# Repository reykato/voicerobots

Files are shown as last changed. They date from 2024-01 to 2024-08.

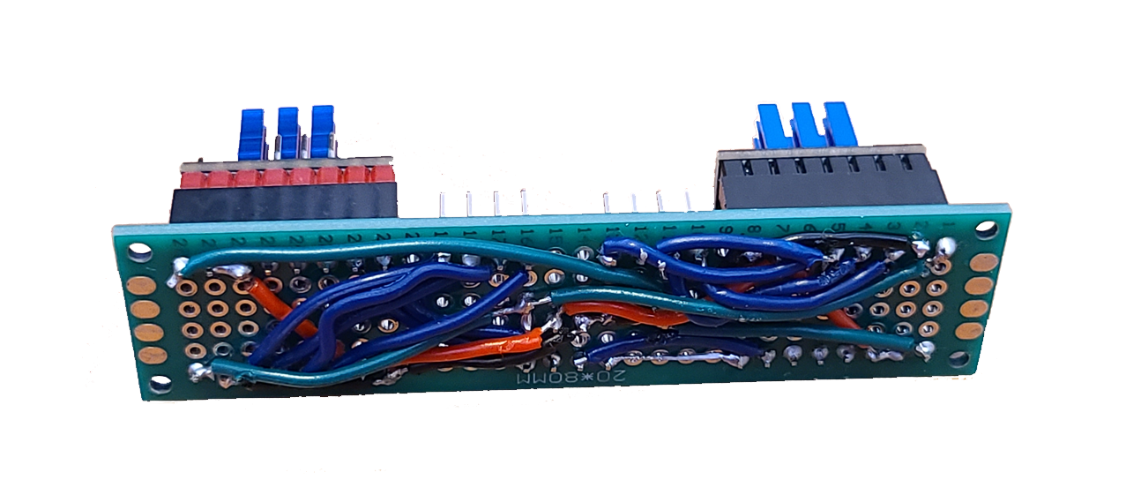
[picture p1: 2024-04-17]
images/stepper_driver_board_2.png

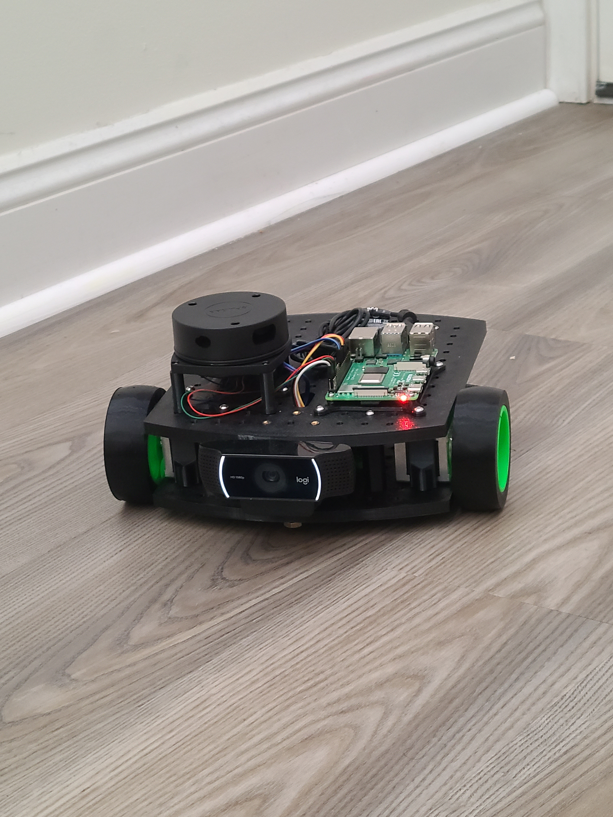
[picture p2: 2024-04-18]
images/robot/20240418_110335.jpg

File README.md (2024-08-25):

# Voice-Controlled Robot with Computer Vision
### CMPSC 488 Senior Capstone Design Project, Penn State Harrisburg, Spring 2024

#### Group Members
Japheth Beiler<br>
Tyler Lindsay<br>
Gabriel Marx

#### Faculty Advisors
Dr. Truong Tran<br>
Dr. Sayed Reza

This project won first prize out of 14 Computer Science projects at the PSU Harrisburg Capstone Design Conference.<br>

This repository is the main repository for this project. The server-side code is held in another repository available here: https://github.com/reykato/voicerobots-server

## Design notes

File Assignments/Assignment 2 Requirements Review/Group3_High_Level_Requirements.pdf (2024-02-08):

Voice-Demanded Robot Project
Group 3: Japheth Beiler, Tyler Lindsay, Gabriel Marx Technical Advisor: Dr. Truong Tran
Faculty Advisor: Dr. Sayed Reza
Fall 2023 - Spring 2024

High Level Requirements

- Filter audio input for easier audio transcription
- Obey direct navigational voice commands
- Use text generative AI to interpret commands that are not specified
- Navigate to specific colored targets
- Reroute navigation around obstacles identified by LiDAR
- Host website with manual joystick-style controls
- Stream live video of the robot’s view to the website
- Stream live 2D point cloud generated by LiDAR to website
- Draw decision-making symbols and lines on the live video to show how the robot “thinks”
- Ability to attach a towable device for transporting supplies

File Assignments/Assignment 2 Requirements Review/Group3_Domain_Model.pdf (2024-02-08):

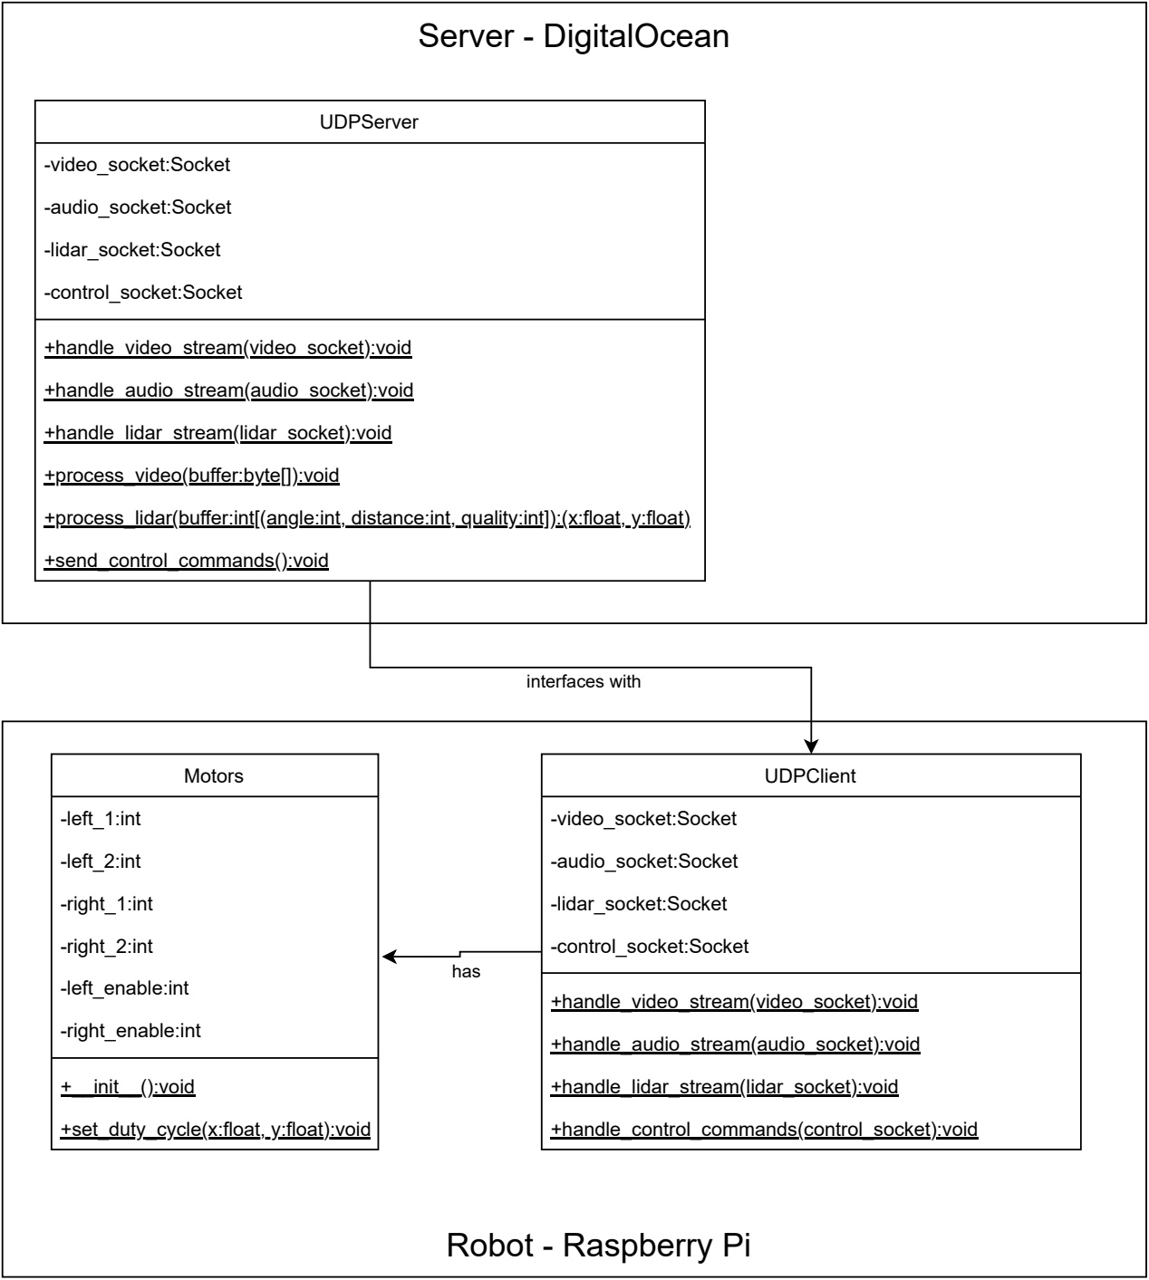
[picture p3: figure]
Motors; -left_1:int; -left_2:int; -right_1:int; -right_2:int; -left_enable:int; -right_enable:int; +__init__():void; +set_duty_cycle(x:float, y:float):void; Robot - Raspberry Pi; UDPClient; -video_socket:Socket; -audio_socket:Socket; -lidar_socket:Socket; -control_socket:Socket; +handle_video_stream(video_socket):void; +handle_audio_stream(audio_socket):void; +handle_lidar_stream(lidar_socket):void; Server - DigitalOcean; interfaces with; UDPServer; +process_video(buffer:byte[]):void; +send_control_commands():void; has

+handle_control_commands(control_socket):void

+process_lidar(buffer:int[(angle:int, distance:int, quality:int]):(x:float, y:float)

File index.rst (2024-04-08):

.. Voice-controlled Robot with Autonomous Navigation documentation master file, created by
   sphinx-quickstart on Sat Apr  6 20:12:07 2024.
   You can adapt this file completely to your liking, but it should at least
   contain the root `toctree` directive.

Welcome to Voice-controlled Robot with Autonomous Navigation's documentation!
=============================================================================

.. automodule:: stream
   :members:
   :undoc-members:
   
.. automodule:: audiostream
   :members:
   :undoc-members:
   
.. automodule:: controlstream
   :members:
   :undoc-members:
   
.. automodule:: videostream
   :members:
   :undoc-members:
   
.. automodule:: lidarstream
   :members:
   :undoc-members:
   
.. automodule:: motors
   :members:
   :undoc-members:

.. toctree::
   :maxdepth: 2
   :caption: Contents:

Indices and tables
==================

* :ref:`genindex`
* :ref:`modindex`
* :ref:`search`

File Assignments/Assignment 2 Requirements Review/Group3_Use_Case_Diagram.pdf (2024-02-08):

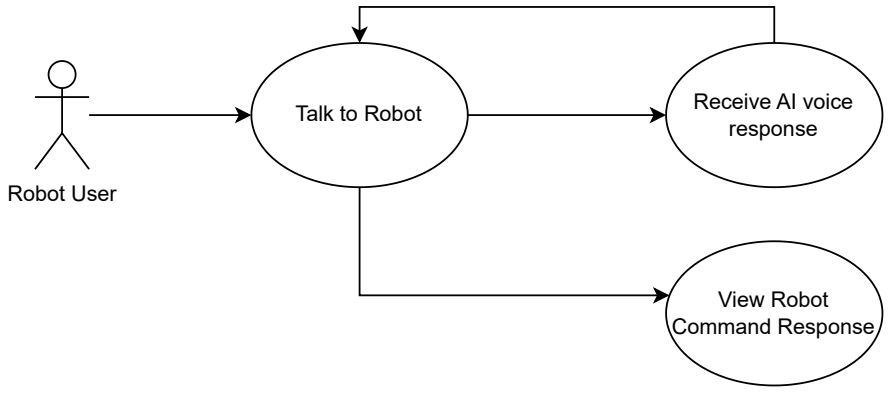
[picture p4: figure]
Robot User; Talk to Robot; View Robot Command Response; Receive AI voice response

Talk to Robot

A Robot User will be able to talk to the robot. The robot will listen using a live audio feed and send the audio data to the server. The server will intuit the speech and either issue a direct command to the robot, or respond in natural language.

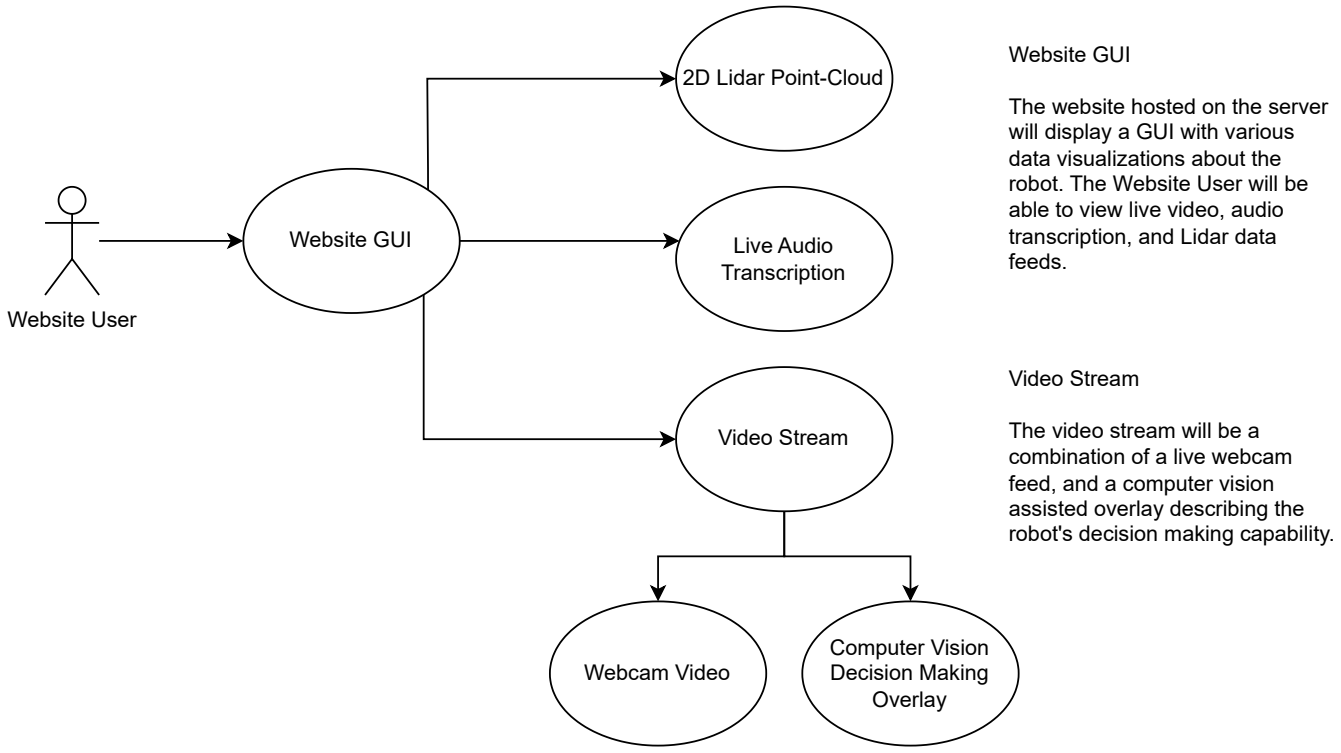
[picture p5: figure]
Website User; Video Stream; 2D Lidar Point-Cloud; Live Audio Transcription; Website GUI; The website hosted on the server will display a GUI with various data visualizations about the robot. The Website User will be able to view live video, audio transcription, and Lidar data feeds.; Webcam Video; Computer Vision Decision Making Overlay; The video stream will be a combination of a live webcam feed, and a computer vision assisted overlay describing the robot's decision making capability.

Robot Manual Controls

An authenticated Website
Administrator will be able to use joystick style controls to issue manual commands to the robot.

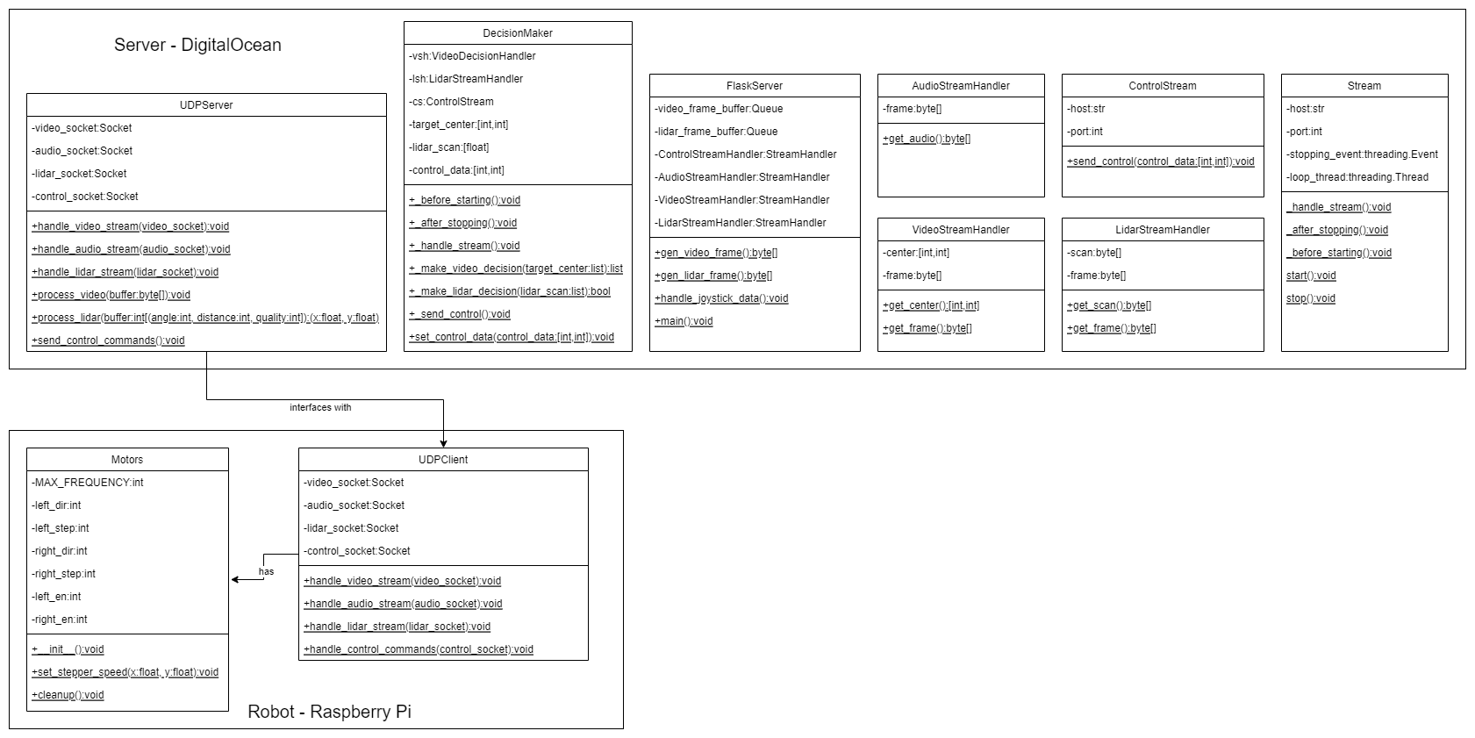
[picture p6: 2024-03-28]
Assignments/Assignment 3 Design Review/Domain_Model_v3.png

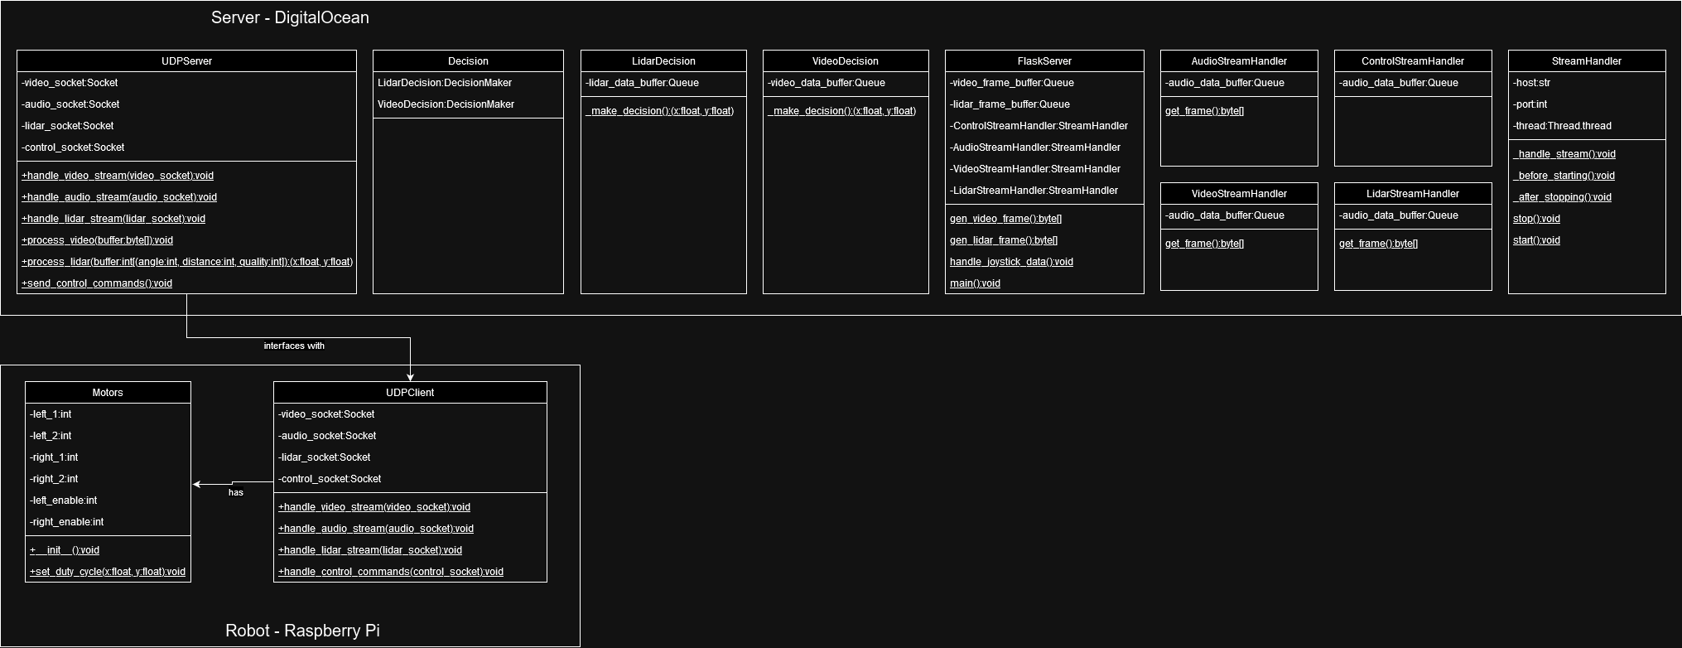
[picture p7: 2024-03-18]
Assignments/Assignment 3 Design Review/Domain_Model_v2.png

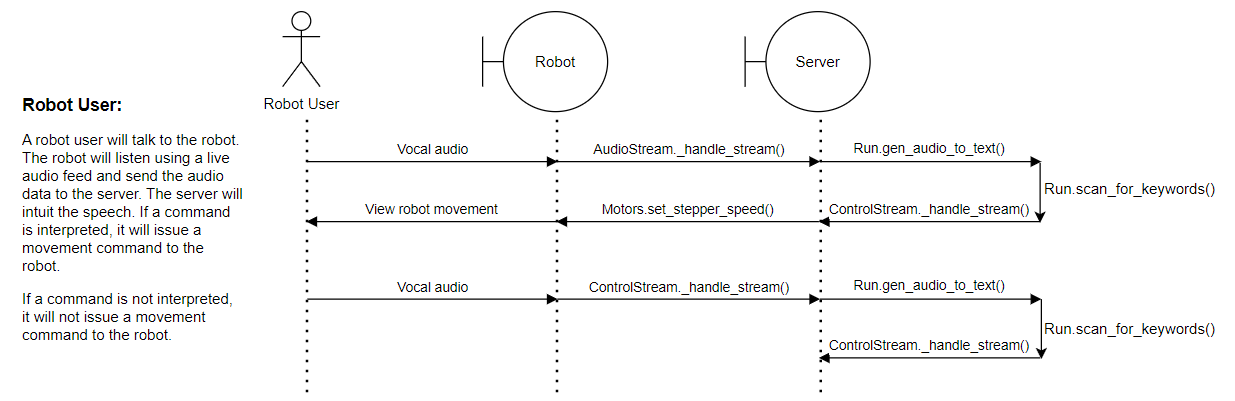
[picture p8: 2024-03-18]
Assignments/Assignment 3 Design Review/Sequence_Diagram_1.png

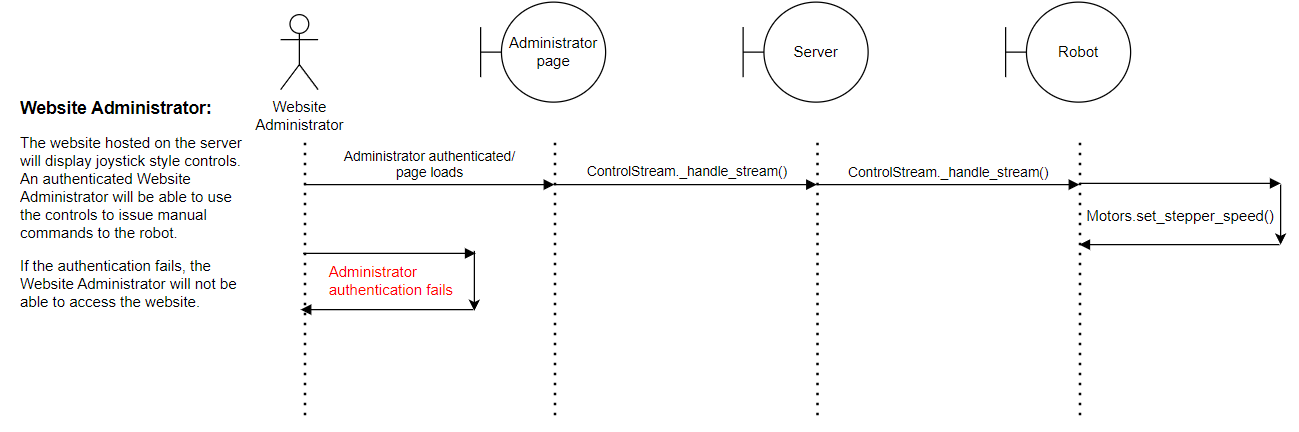
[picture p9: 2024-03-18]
Assignments/Assignment 3 Design Review/Sequence_Diagram_3.png

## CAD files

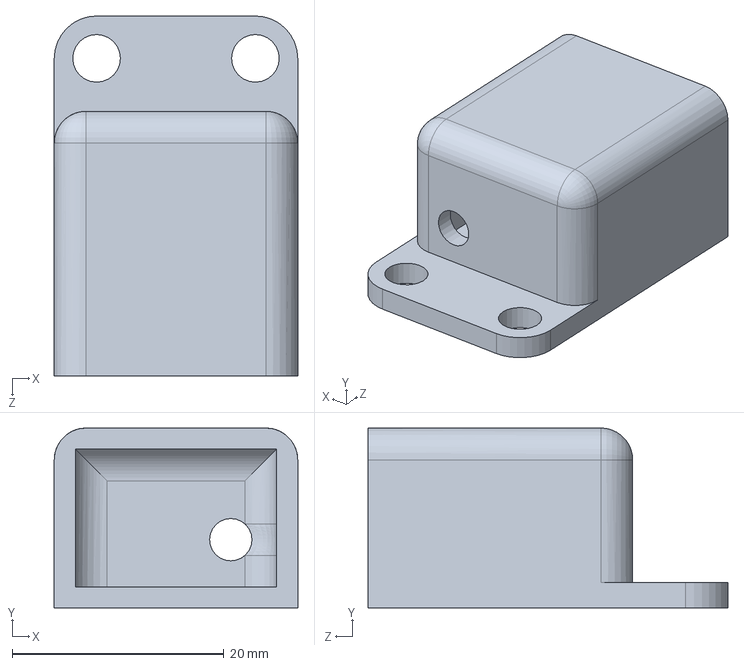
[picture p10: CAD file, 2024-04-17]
models/Power_Switch_Mount_RevA.SLDPRT
23.0 x 17.0 x 34.0 mm

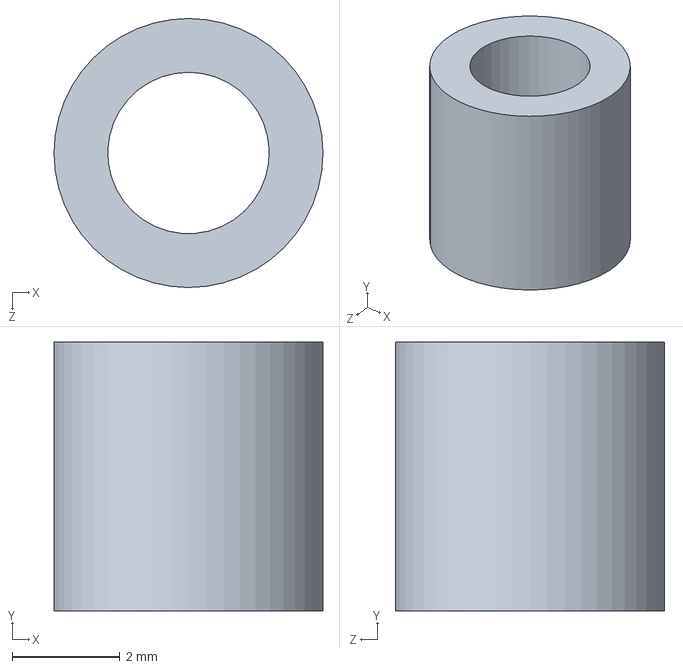
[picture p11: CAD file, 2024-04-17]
models/Circuit_Board_Spacer_RevA.SLDPRT
5.00 x 5.00 x 5.00 mm

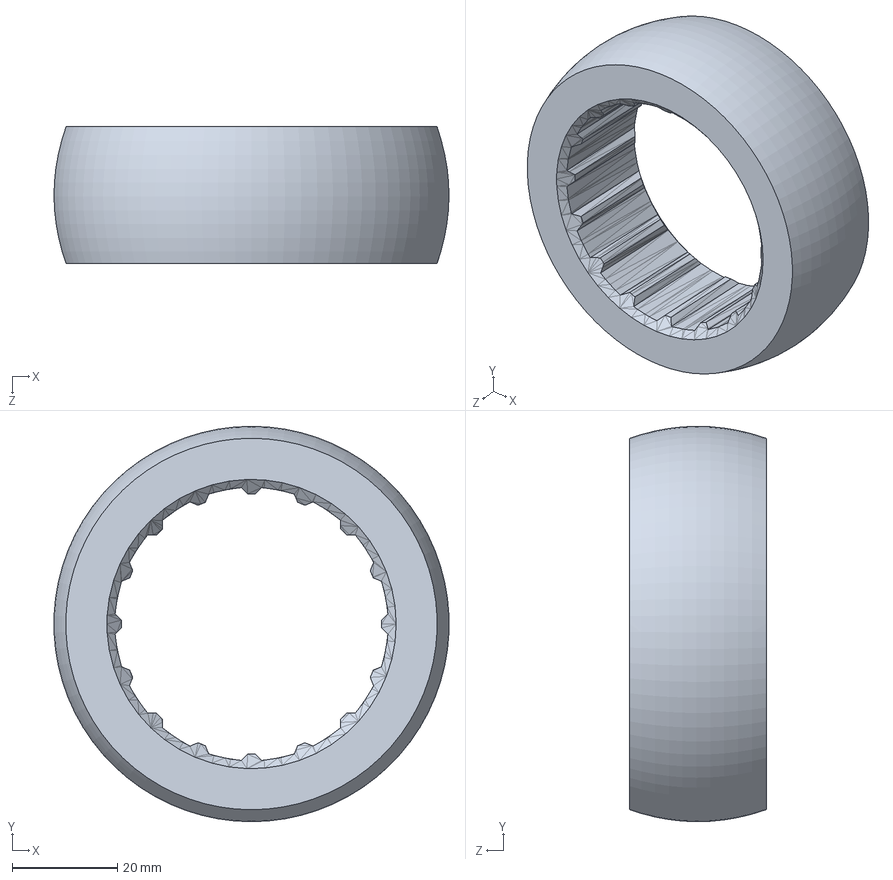
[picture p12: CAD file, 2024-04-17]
models/10OffTire2_Modified_RevA.SLDPRT
75.1 x 75.2 x 26.0 mm

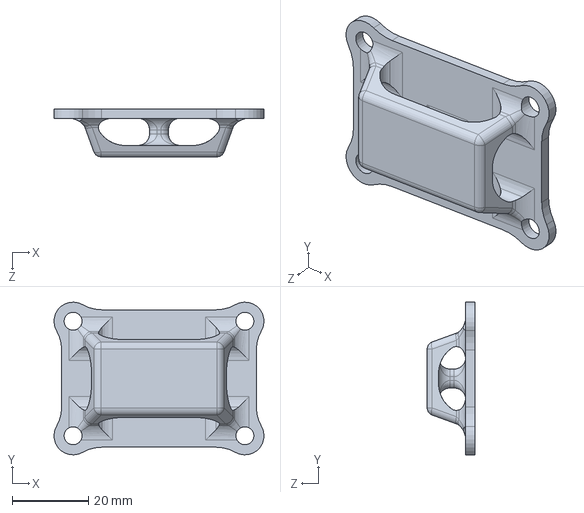
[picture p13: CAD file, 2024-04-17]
models/Slider_Foot_RevA.SLDPRT
55.0 x 40.0 x 12.5 mm

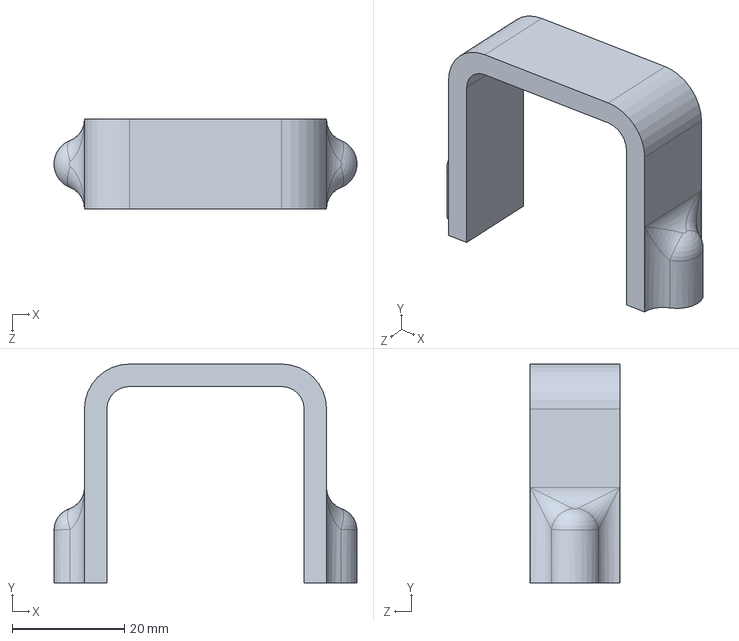
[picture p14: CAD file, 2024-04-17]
models/Stepper_Motor_Mount_RevA.SLDPRT
54.0 x 39.0 x 16.0 mm

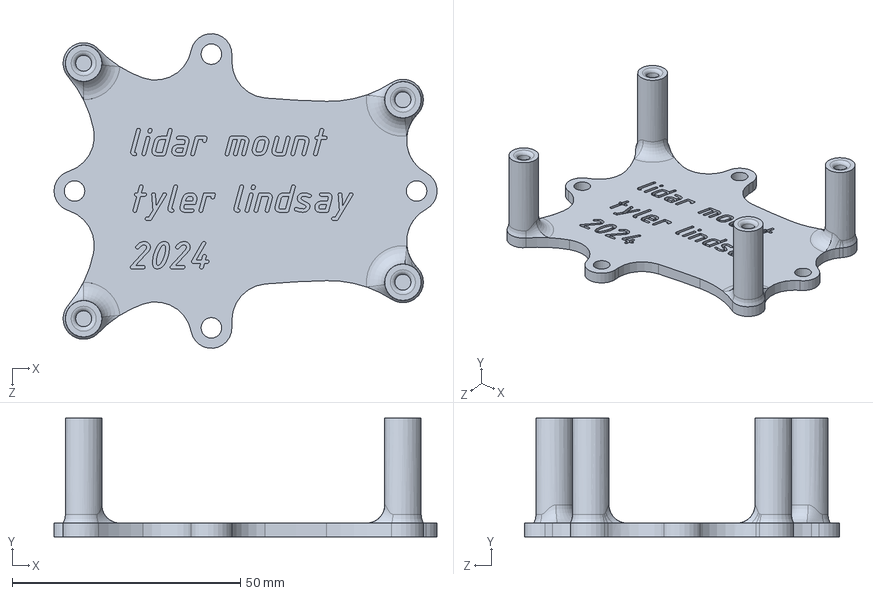
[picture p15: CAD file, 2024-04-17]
models/LiDAR_Mount_RevA.SLDPRT
84.0 x 26.0 x 69.0 mm

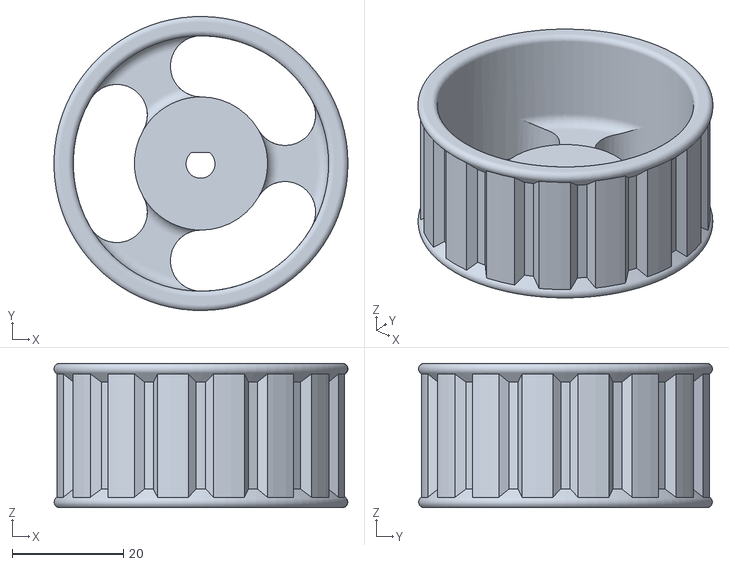
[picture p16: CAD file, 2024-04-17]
models/10Wheel3_Modified_RevA.STL
53.0 x 53.0 x 26.0

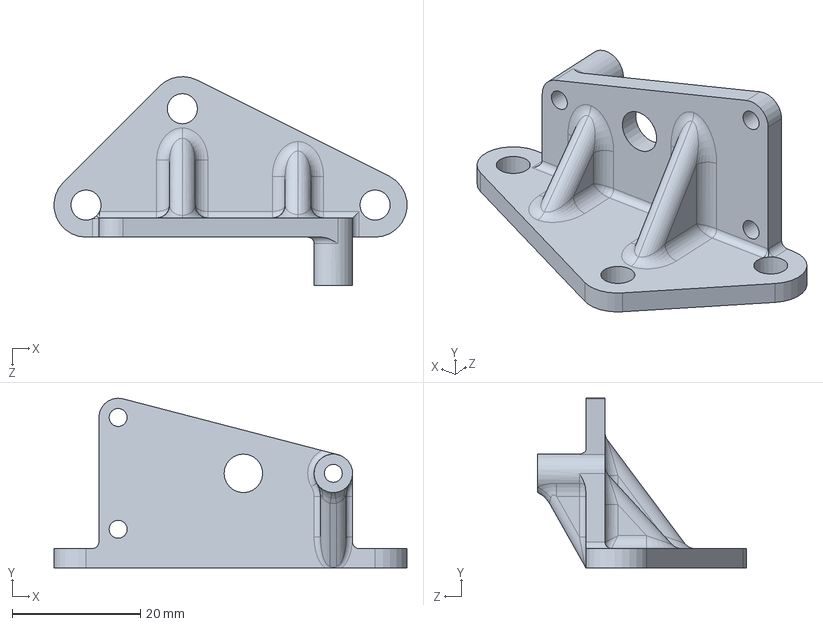
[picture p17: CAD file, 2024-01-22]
models/Motor_Mount_RevB.SLDPRT
55.0 x 26.4 x 32.5 mm

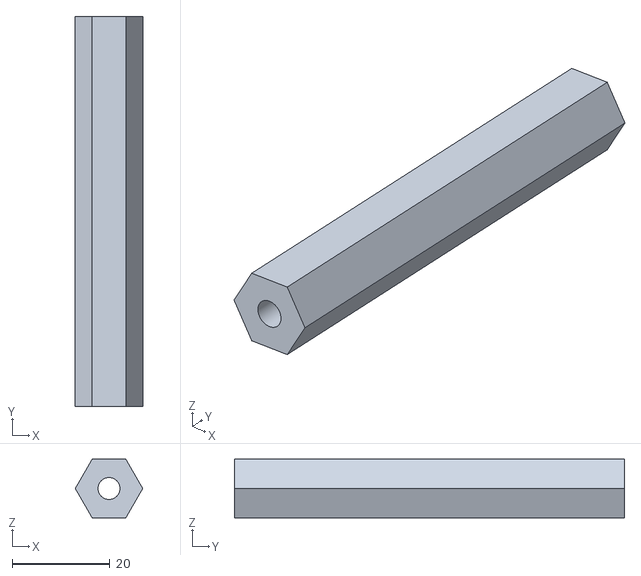
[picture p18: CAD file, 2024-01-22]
models/80mm_Riser_RevA.STL
13.9 x 80.0 x 12.0

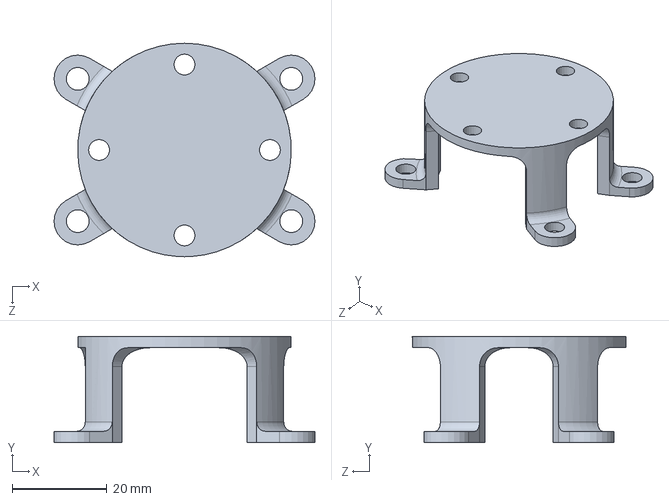
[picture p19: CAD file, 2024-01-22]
models/Caster_Mount_RevA.SLDPRT
55.0 x 22.4 x 45.0 mm

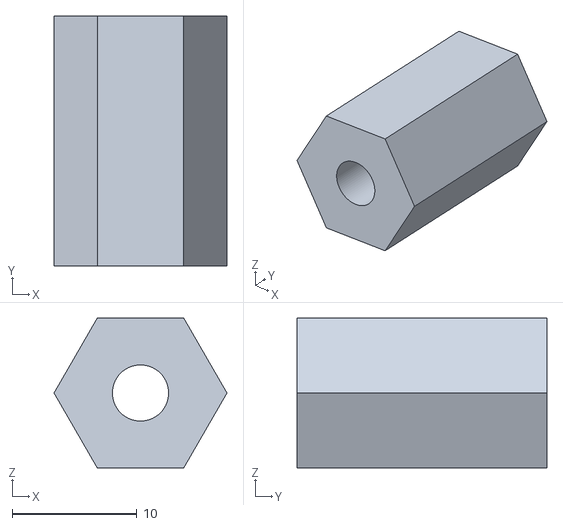
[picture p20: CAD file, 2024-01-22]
models/20mm_Riser_RevA.STL
13.9 x 20.0 x 12.0

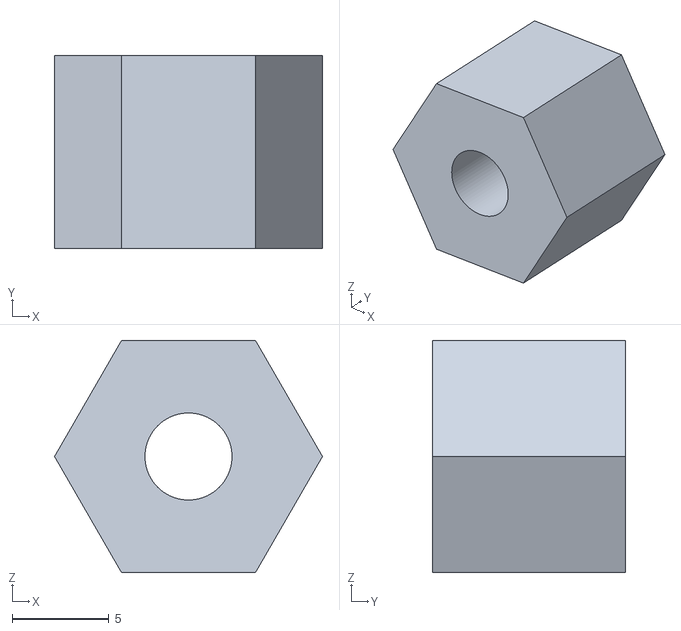
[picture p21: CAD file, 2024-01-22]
models/10mm_Riser_RevA.STL
13.9 x 10.0 x 12.0

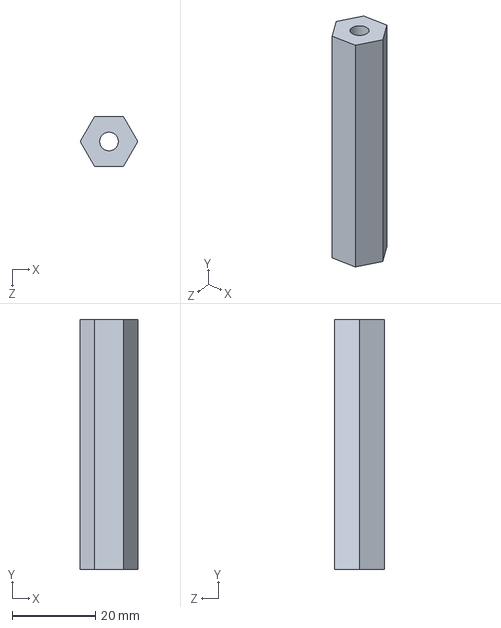
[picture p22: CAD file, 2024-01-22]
models/60mm_Riser_RevA.SLDPRT
13.9 x 60.0 x 12.0 mm

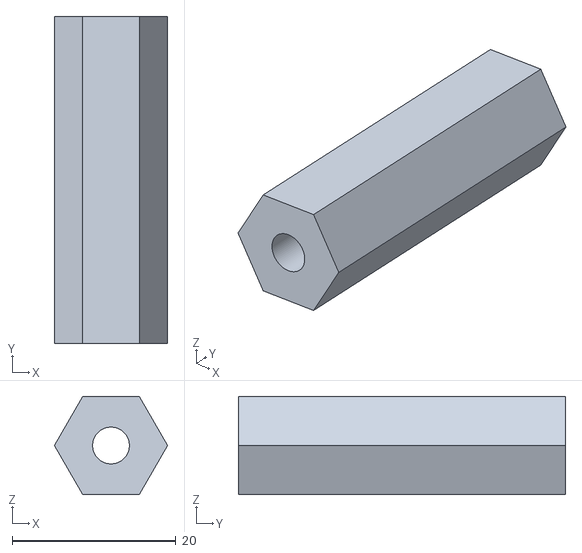
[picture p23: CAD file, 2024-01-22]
models/40mm_Riser_RevA.STL
13.9 x 40.0 x 12.0

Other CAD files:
models/Robot_Frame_RevA.SLDPRT
models/Battery_Pack_Box_RevA.SLDPRT
models/Raspberry_Pi_Mount_RevA.SLDPRT
models/05mm_Riser_RevA.STL
models/10OffTire2_Modified_RevA.STL
models/60mm_Riser_RevA.STL
models/Battery_Pack_Box_RevA.STL
models/Caster_Mount_RevA.STL
models/Circuit_Board_Spacer_RevA.STL
models/LiDAR_Mount_RevA.STL
models/Motor_Mount_RevA.SLDPRT
models/Motor_Mount_RevA.STL
models/Motor_Mount_RevB.STL
models/Raspberry_Pi_Mount_RevA.STL
models/Robot_Frame_RevA.STL
models/Slider_Foot_RevA.STL
models/Stepper_Motor_Mount_RevA.STL

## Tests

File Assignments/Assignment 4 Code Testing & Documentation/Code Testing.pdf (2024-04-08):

Group 3: Voice-Controlled Robot Assignment 4: Code Testing
6 April 2024

### Test cases for voicerobots-server/src/decisionmaker.py

Test Case ID: 1
Test Priority (Low/Medium/High): High Module Name: decisionmaker.py
Test Designed & Executed By: Japheth Beiler
Test Design Date: 4 April 2024
Step | Test Name | Class & Method | Test Data/ Parameters | Expected Result | Actual Result | Status (Pass/ Fail) | Comments
1 | test_handle_stream_sto p_robot | Class: DecisionMaker Method: _handle_stream | target_center: [480, 100] lidar_scan: [90, 100, 70] | control_data: [0, 0] | control_data: [0, 0] | Pass
2 | test_handle_stream_co ntinue_moving | Class: DecisionMaker Method: _handle_stream | target_center: [480, 100] lidar_scan: [60, 80, 110] | control_data: [0, 0.4] | control_data: [0, 0.4] | Pass
3 | test_make_video_decis ion | Class: DecisionMaker Method: _make_video_decision | target_center: [600, 100] | video_control_ decision: [0.125, 0] | video_control_ decision: [0.125, 0] | Pass

4 | test_make_video_decis ion | Class: DecisionMaker Method: _make_video_decision | target_center: [300, 100] | video_control_ decision: [-0.1875, 0] | video_control_ decision: [-0.1875, 0] | Pass
5 | test_make_video_decis ion | Class: DecisionMaker Method: _make_video_decision | target_center: [480, 100] | video_control_ decision: [0, 0.4] | video_control_ decision: [0, 0.4] | Pass
6 | test_make_video_decis ion | Class: DecisionMaker Method: _make_video_decision | target_center: [0, 0] | video_control_ decision: [0, 0] | video_control_ decision: None | Fail | Returning “None” here won’t break anything, but it should probably be fixed
7 | test_make_lidar_decisi on | Class: DecisionMaker Method: _make_lidar_decision | lidar_scan: [] | stop_robot: False | stop_robot: False | Pass
8 | test_make_lidar_decisi on | Class: DecisionMaker Method: _make_lidar_decision | lidar_scan: [[60, 80, 110]] | stop_robot: False | stop_robot: False | Pass
9 | test_make_lidar_decisi on | Class: DecisionMaker Method: _make_lidar_decision | lidar_scan: [[90, 100, 70]] | stop_robot: True | stop_robot: True | Pass

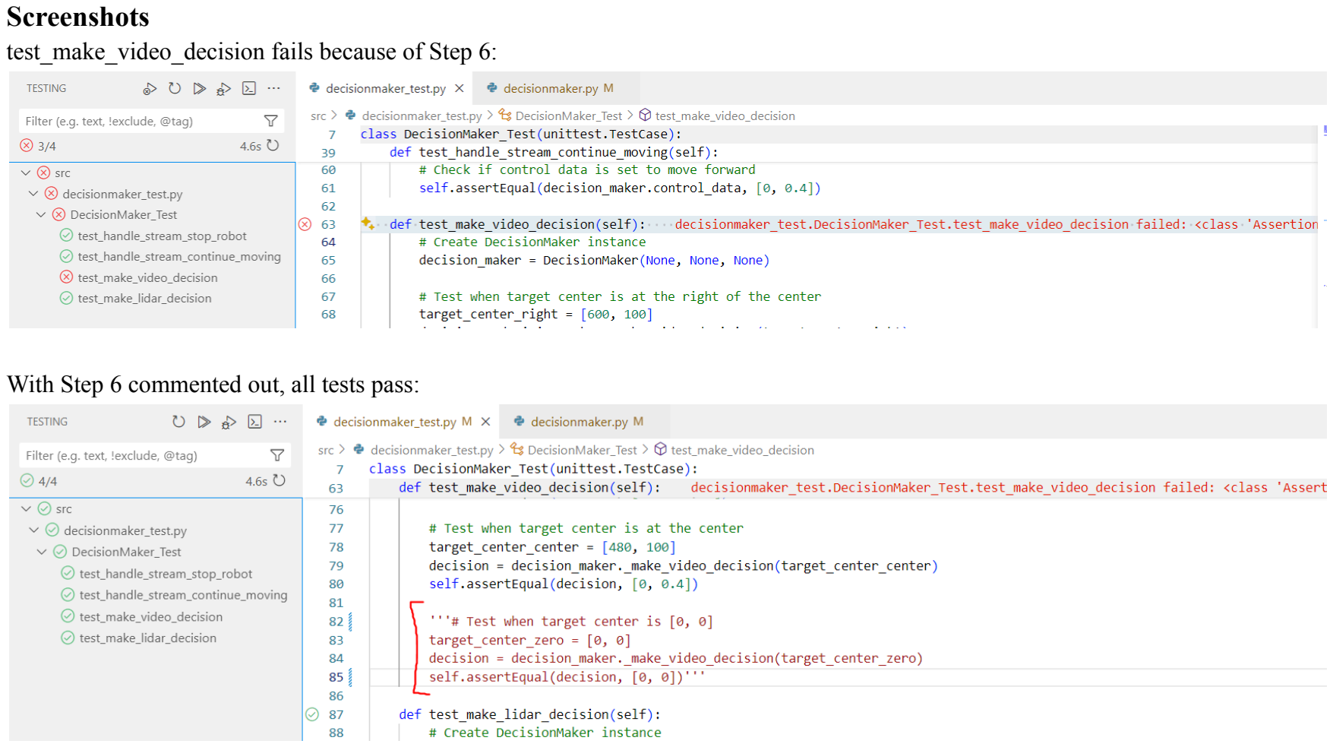
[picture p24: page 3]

Screenshots
test_make_video_decision fails because of Step 6:

With Step 6 commented out, all tests pass:

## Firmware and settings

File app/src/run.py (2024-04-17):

from videostream import VideoStream
from controlstream import ControlStream
from audiostream import AudioStream
from lidarstream import LidarStream

HOST_IP = "159.65.162.35"
# HOST_IP = "10.20.9.254"
VIDEO_HOST_PORT = 5005
CONTROL_HOST_PORT = 5006
AUDIO_HOST_PORT = 5007
LIDAR_HOST_PORT = 5008

CAMERA_ADDRESS = 0

vs = VideoStream(HOST_IP, VIDEO_HOST_PORT, 10, CAMERA_ADDRESS)
csh = ControlStream(HOST_IP, CONTROL_HOST_PORT)
aus = AudioStream(HOST_IP, AUDIO_HOST_PORT)
ls = LidarStream(HOST_IP, LIDAR_HOST_PORT)

def main():
    vs.start()
    csh.start()
    # aus.start()
    ls.start()
    input("Stream started. Press ENTER to stop.")
    csh.stop()
    vs.stop()
    # aus.stop()
    ls.stop()

if __name__ == '__main__':
    try:
        main()
    except KeyboardInterrupt:
        csh.stop()
        # aus.stop()
        vs.stop()
        ls.stop()

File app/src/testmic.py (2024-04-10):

import speech_recognition as sr
from queue import Queue
from time import sleep

def main():
    data_queue = Queue()
    recorder = sr.Recognizer()
    recorder.dynamic_energy_threshold = False
    source = sr.Microphone(sample_rate=16000)
    with source:
        recorder.adjust_for_ambient_noise(source)
    def record_callback(_, audio:sr.AudioData) -> None:
        data = audio.get_raw_data()
        data_queue.put(data)
    recorder.listen_in_background(source, record_callback, phrase_time_limit=5)
    while True:
        try:
            if not data_queue.empty():
                data_queue.queue.clear()
                print("received audio")
            else:
                # Infinite loops are bad for processors, must sleep.
                sleep(0.25)
        except KeyboardInterrupt:
            break

if __name__ == "__main__":
    main()

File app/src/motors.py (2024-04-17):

import RPi.GPIO as GPIO          

class Motors:
    '''
    Abstracts GPIO initialization and PWM
    signal management to provide functions for moving the robot.

    Parameters:
        - left_dir (int): direction pin of left motor
        - left_step (int): step pin of left motor
        - right_dir (int): direction pin of right motor
        - right_step (int): step pin of right motor
        - left_en (int): enable pin of left motor, active low
        - right_en (int): enable pin of right motor, active low
    '''
    MAX_FREQUENCY = 6000

    def __init__(self, left_dir, left_step, right_dir, right_step, left_en, right_en):
        self.left_dir = left_dir
        self.left_step = left_step
        self.right_dir = right_dir
        self.right_step = right_step
        self.left_en = left_en
        self.right_en = right_en

        # setup motor control pins as outputs
        GPIO.setmode(GPIO.BCM)
        self.cleanup()

        GPIO.setup(left_dir, GPIO.OUT)
        GPIO.setup(left_step, GPIO.OUT)
        GPIO.setup(right_dir, GPIO.OUT)
        GPIO.setup(right_step, GPIO.OUT)
        GPIO.setup(left_en, GPIO.OUT)
        GPIO.setup(right_en, GPIO.OUT)

        GPIO.output(left_dir, GPIO.LOW)
        GPIO.output(right_dir, GPIO.LOW)
        GPIO.output(left_en, GPIO.HIGH)
        GPIO.output(right_en, GPIO.HIGH)

        self.left_pwm = GPIO.PWM(left_step, 100)
        self.right_pwm = GPIO.PWM(right_step, 100)

        self.left_pwm.start(50)
        self.right_pwm.start(50)

    def set_stepper_speed(self, x, y):
        '''
        Sets direction and speed of stepper motors based on x and y inputs
        on the interval [-1, 1].
        The robot will be stationary with (0, 0), move straight forward with
        (0, 1), rotate left with (-1, 0), etc.
        
        Parameters:
            - x (int): turning/rotation
            - y (int): forward/backward movement
        '''
        # Calculate motor speeds
        left_speed = (y + x) / 2
        right_speed = (y - x) / 2

        # Ensure motor speeds are within valid range [-1, 1]
        left_speed = max(min(left_speed, 1), -1)
        right_speed = max(min(right_speed, 1), -1)

        if left_speed == 0:
            GPIO.output(self.left_en, GPIO.HIGH)
        else:
            GPIO.output(self.left_en, GPIO.LOW)

        if right_speed == 0:
            GPIO.output(self.right_en, GPIO.HIGH)
        else:
            GPIO.output(self.right_en, GPIO.LOW)

        if left_speed < 0:
            GPIO.output(self.left_dir, GPIO.LOW)
        else:
            GPIO.output(self.left_dir, GPIO.HIGH)

        if right_speed < 0:
            GPIO.output(self.right_dir, GPIO.HIGH)
        else:
            GPIO.output(self.right_dir, GPIO.LOW)

        print(f"Left speed: {left_speed}, Right speed: {right_speed}")
        self.left_pwm.ChangeFrequency(max(self.MAX_FREQUENCY * abs(left_speed), 100))
        self.right_pwm.ChangeFrequency(max(self.MAX_FREQUENCY * abs(right_speed), 100))
            
    def cleanup(self):
        GPIO.cleanup()

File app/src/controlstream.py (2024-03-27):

import socket
import time
import numpy as np
from motors import Motors
from stream import Stream

class ControlStream(Stream):
    motors = Motors(20, 21, 12, 16, 7, 1) # initialize motors with GPIO pin numbers

    def _handle_stream(self):
        while not self.stop_event.is_set():
            try:
                received_data = self.socket.recv(1024)
                if not received_data is None:
                    decoded_data = np.frombuffer(received_data, dtype=np.float32)
                    if len(decoded_data) != 0:
                        print(f"Received control: {decoded_data}")
                        x = decoded_data[0]
                        y = decoded_data[1]
                        self.motors.set_stepper_speed(x, y)
                    else:
                        self._connect_to_server()
            except socket.error as e:
                received_data = None
                if not e.args[0] == 'timed out':
                    print(f"Error: '{e.args[0]}', reconnecting...")
                    self._connect_to_server()

    def _connect_to_server(self):
        while True:
            try:
                print("Trying to connect to server...")
                self.socket.connect((self.host, self.port))
                break  # Exit the loop if connection succeeds
            except socket.error:
                print("Failed to connect, retrying in 1 second...")
                time.sleep(1)  # Wait for 1 second before trying again
            except KeyboardInterrupt:
                print("Connection attempt cancelled.")
                self._after_stopping()
                break

    def _before_starting(self):
        self.socket = socket.socket(socket.AF_INET, socket.SOCK_STREAM)
        self._connect_to_server()
        self.socket.settimeout(0.2)

    def _after_stopping(self):
        self.socket.close()
        self.motors.cleanup()

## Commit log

2024-01-22 initial push of models
    [05mm_Riser_RevA.STL, 10mm_Riser_RevA.STL, 20mm_Riser_RevA.STL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]
2024-01-22 added dual motor support to run.py for testing
2024-01-23 fix run.py (for real this time)
    [run.py]
2024-01-23 added script to fix socketio
2024-01-23 fixed incorrect function name
    [motors.py]
2024-01-23 fix duty cycle code
    [motors.py]
2024-01-23 fix duty cycle again
    [motors.py]
2024-01-24 streamline motors functions
2024-01-24 SpeechRecognition, currently writes to a .wav file
2024-01-29 fixed typo in motors.py
    [motors.py]
2024-02-01 camera test
2024-02-07 add lidar.py
2024-02-07 update lidar.py with ttyS0 port
2024-02-07 printing measurements
2024-02-07 print individual scans
2024-02-14 reword and fix comments, fix super() call
    [stream.py, videostream.py]
2024-02-20 up frame rate
2024-02-20 was double-reading frames!
2024-02-20 make socket non-blocking
2024-02-20 socket.timeout was wrong
2024-02-21 add speed modifier to motors
2024-02-21 try clearing camera buffer continuously for lower latency
2024-02-22 fix timeout and add reconnection to controlstreamhandler
    [controlstreamhandler.py]
2024-02-27 update motors for steppers
2024-02-29 update pin numbers for tmc2209 stepper drivers
2024-02-29 fix wrong function call name
    [motors.py]
2024-02-29 fix 0 frequency in changefrequency code
    [motors.py]
2024-02-29 add debug motor file
2024-02-29 fix duplicate left_pwm setting
    [motors.py]
2024-02-29 fix pin assignment on motor test
2024-02-29 add debug code to motors.py
2024-03-01 adjust max speed and gpio pin numbers
2024-03-01 change right motor direction since it is inverted
    [motors.py]
2024-03-01 add power saving measures to motor controls
2024-03-02 44100kHz sample rate -> 16000kHz, default supported by rpi
2024-03-02 max frequency = 1400Hz
2024-03-02 force float type for frequency, integer values freeze motors
2024-03-04 add lidar stream class
2024-03-04 set motor output pin
2024-03-04 fix pin assignment
2024-03-05 exception handling for lidar scan iterator
2024-03-05 better exception handling for lidar initialization
2024-03-05 add delay to sending lidar data
2024-03-05 prevent crashing when server connection is lost
    [controlstream.py]
2024-03-05 prevent errors and handle CTRL+C
    [controlstream.py, lidarstream.py, motors.py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]
2024-03-05 add further error handling
    [lidarstream.py]
2024-03-05 fix TCP -> UDP for lidarstream
    [lidarstream.py]
2024-03-21 Fix loop stopping issue in Stream class
    [stream.py]
2024-03-21 Fix loop stopping issue and enable frame capture in VideoStream
    [stream.py, videostream.py]
2024-03-21 Add socket timeout to audio and video streams
2024-03-21 Add socket timeout to LidarStream class
2024-03-21 Update video stream frame rate to 10
2024-03-27 Refactor control stream and add print statement for motor speeds to debug
2024-03-27 Add print statement to display received control data
2024-04-11 See if lidar noise is the issue
    [lidarstream.py]
2024-04-17 Add new images and models
    [10OffTire2_Modified_RevA.SLDPRT, 10OffTire2_Modified_RevA.STL, 10Wheel3_Modified_RevA.STL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]
2024-04-17 Fix motor cleanup in motors.py
    [motors.py]
